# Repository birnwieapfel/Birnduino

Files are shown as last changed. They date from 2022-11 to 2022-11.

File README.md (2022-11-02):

# birnduino
An Arduino clone with an RS232 serial interface.

In 2013, I bought a board call "Freeduino Serial v2.0", which is an Arduino clone having an RS232 serial interface using a MAX232. But it seems that it is not available anymore now and I could not find the original files of the "v2.0". So I decided to create my own based on some information about the Freeduino I found in the internet and having a look at my "Freeduino Serial v2.0" board...

## Repository content
- The [inputs folder](inputs) contains the resources which helped me to create the schematic and PCB
- The [datasheets folder](datasheets) contains the datasheets for the used ICs
- The KiCad 6.0 files for the schematic and PCB are in the [KiCad subfolder](KiCad)
- *to come...* Image(s) of the PCB can be found in the folder *images*

## Old resouces
Here are some links which helped to realize this project:
- https://thdarduino.blogspot.com/2015/12/freeduino-serial-v20-bausatz.html

## Other links
- https://freeduino.org/freeduino_open_designs-html
- https://github.com/WestfW/Freeduino-historical

## License
Copyright 2022, Robert Birn. All Rights Reserved.

"birnduino" is licensed under [CC BY-SA 4.0](https://creativecommons.org/licenses/by-sa/4.0/legalcode) by Robert Birn.

This work, "birnduino", is a derivative of "Freeduino Serial" by CircuitJoy and Spiffed, released under CC BY-SA 2.5. 

"Freeduino Serial" is based on the Arduino Diecimila reference design (www.arduino.cc/main/ArduinoBoardDiecimila).

I started the work by using the **Arduino KiCad Library**, available here: https://github.com/Alarm-Siren/arduino-kicad-library. Remark: After an update, no reference to this library is existing anymore.

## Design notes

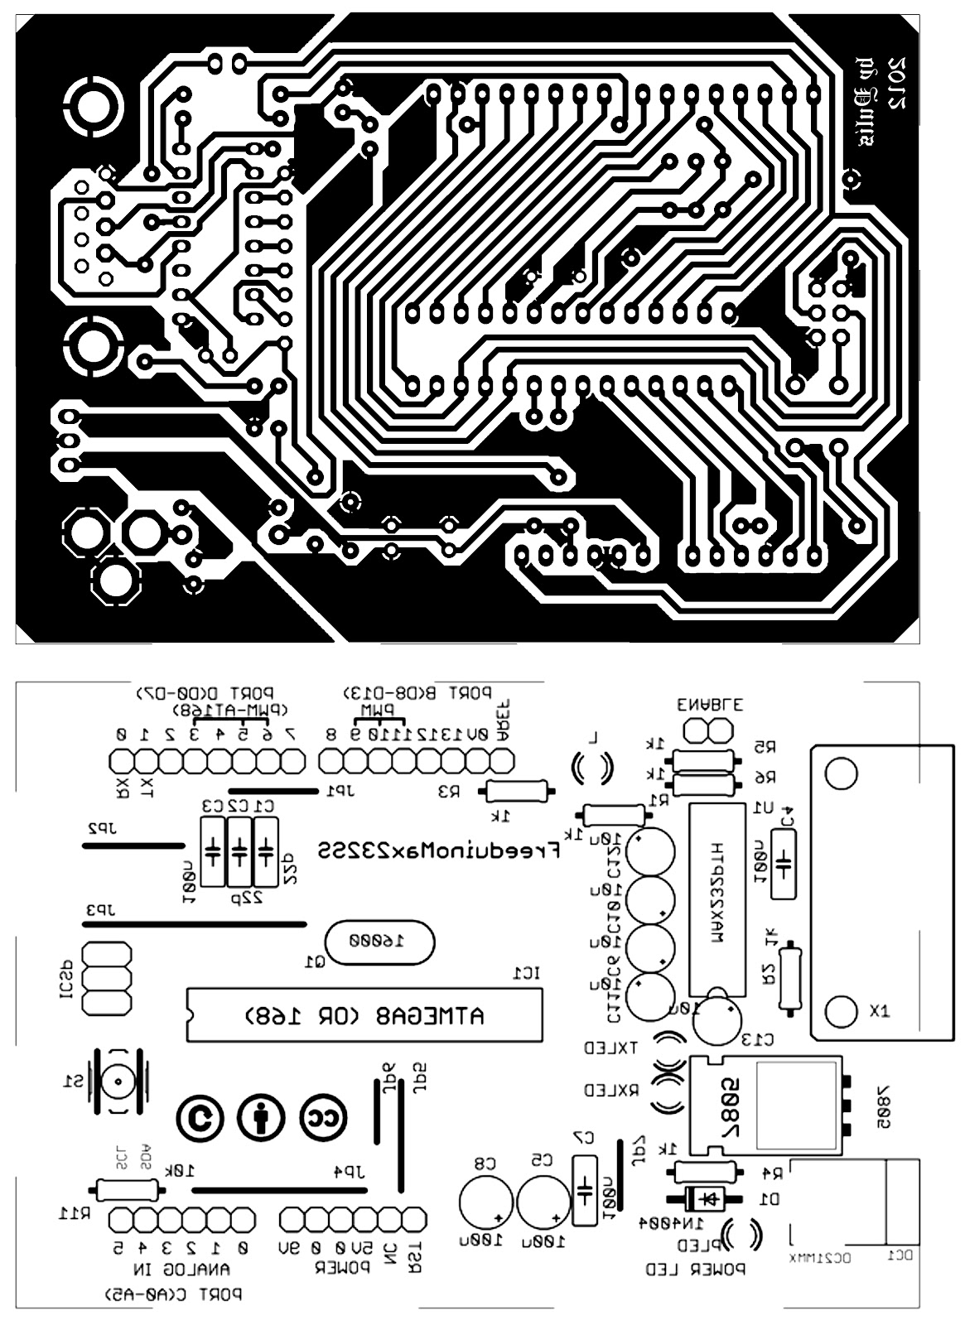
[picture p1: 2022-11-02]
inputs/arduino-serial-board-pcb.jpg

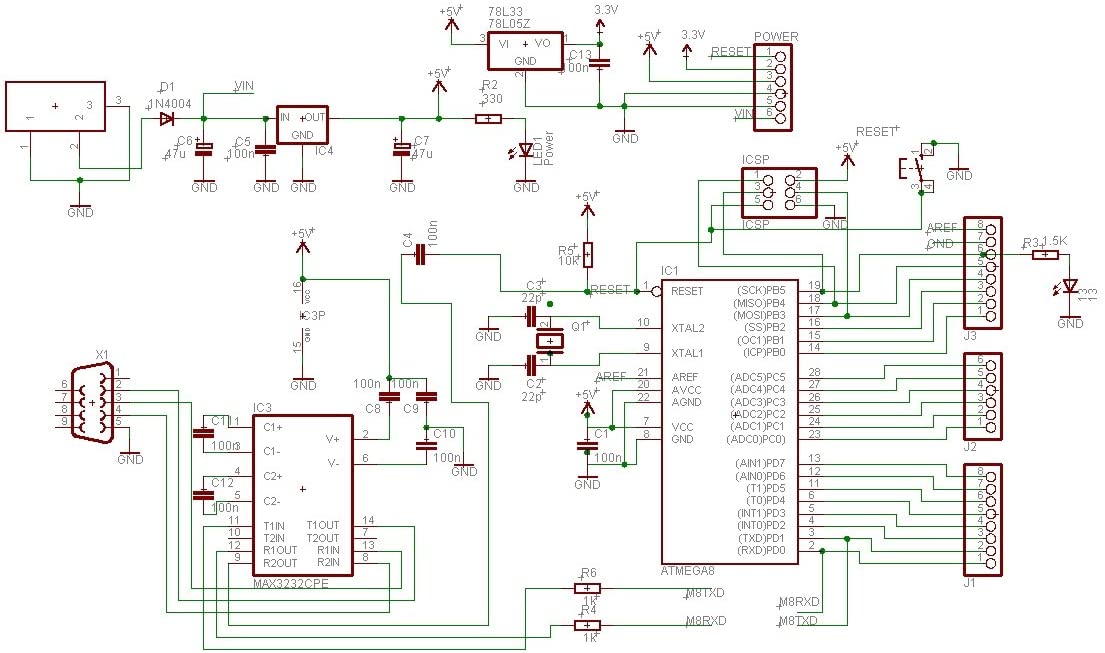
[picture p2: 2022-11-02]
inputs/arduino-serial-board-v2.0.jpg

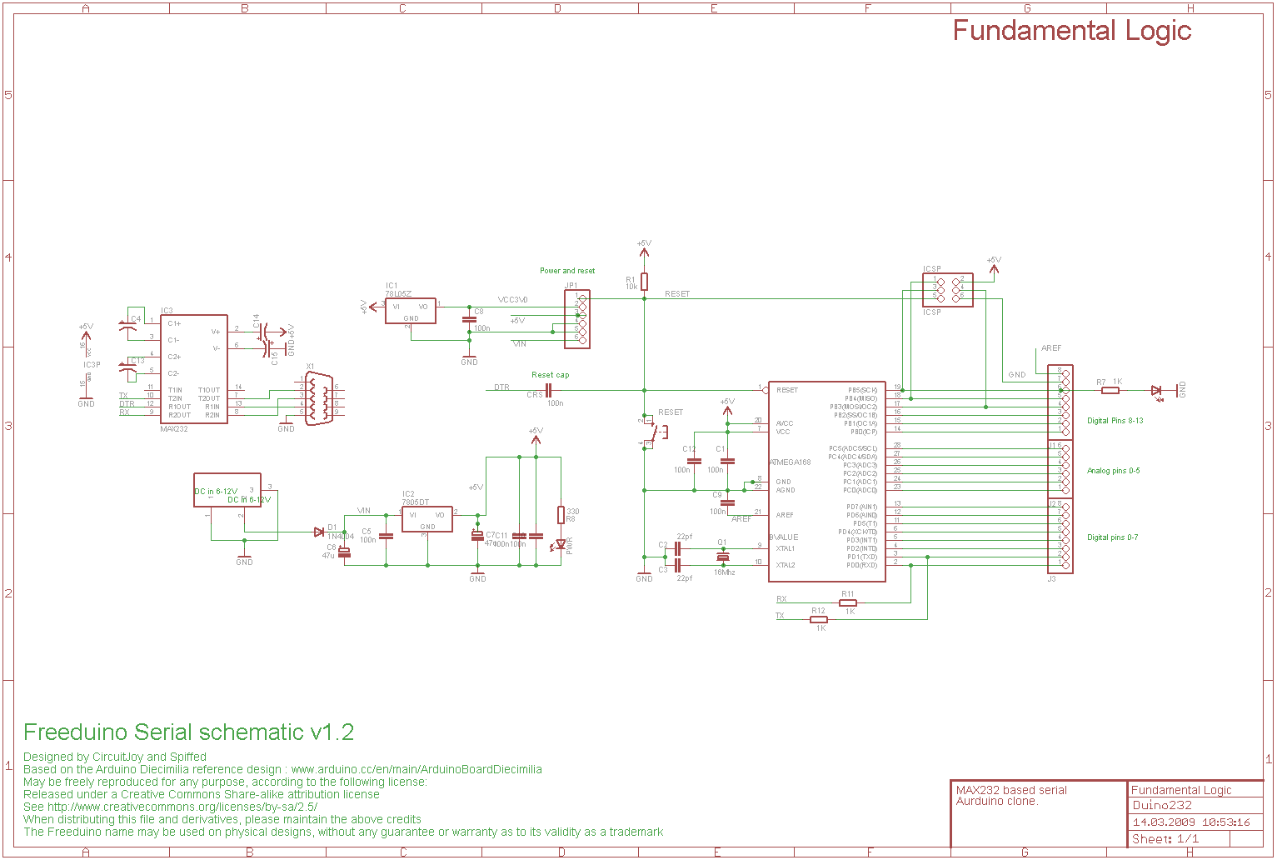
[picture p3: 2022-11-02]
inputs/freeduino_MaxSerial_scheme.gif

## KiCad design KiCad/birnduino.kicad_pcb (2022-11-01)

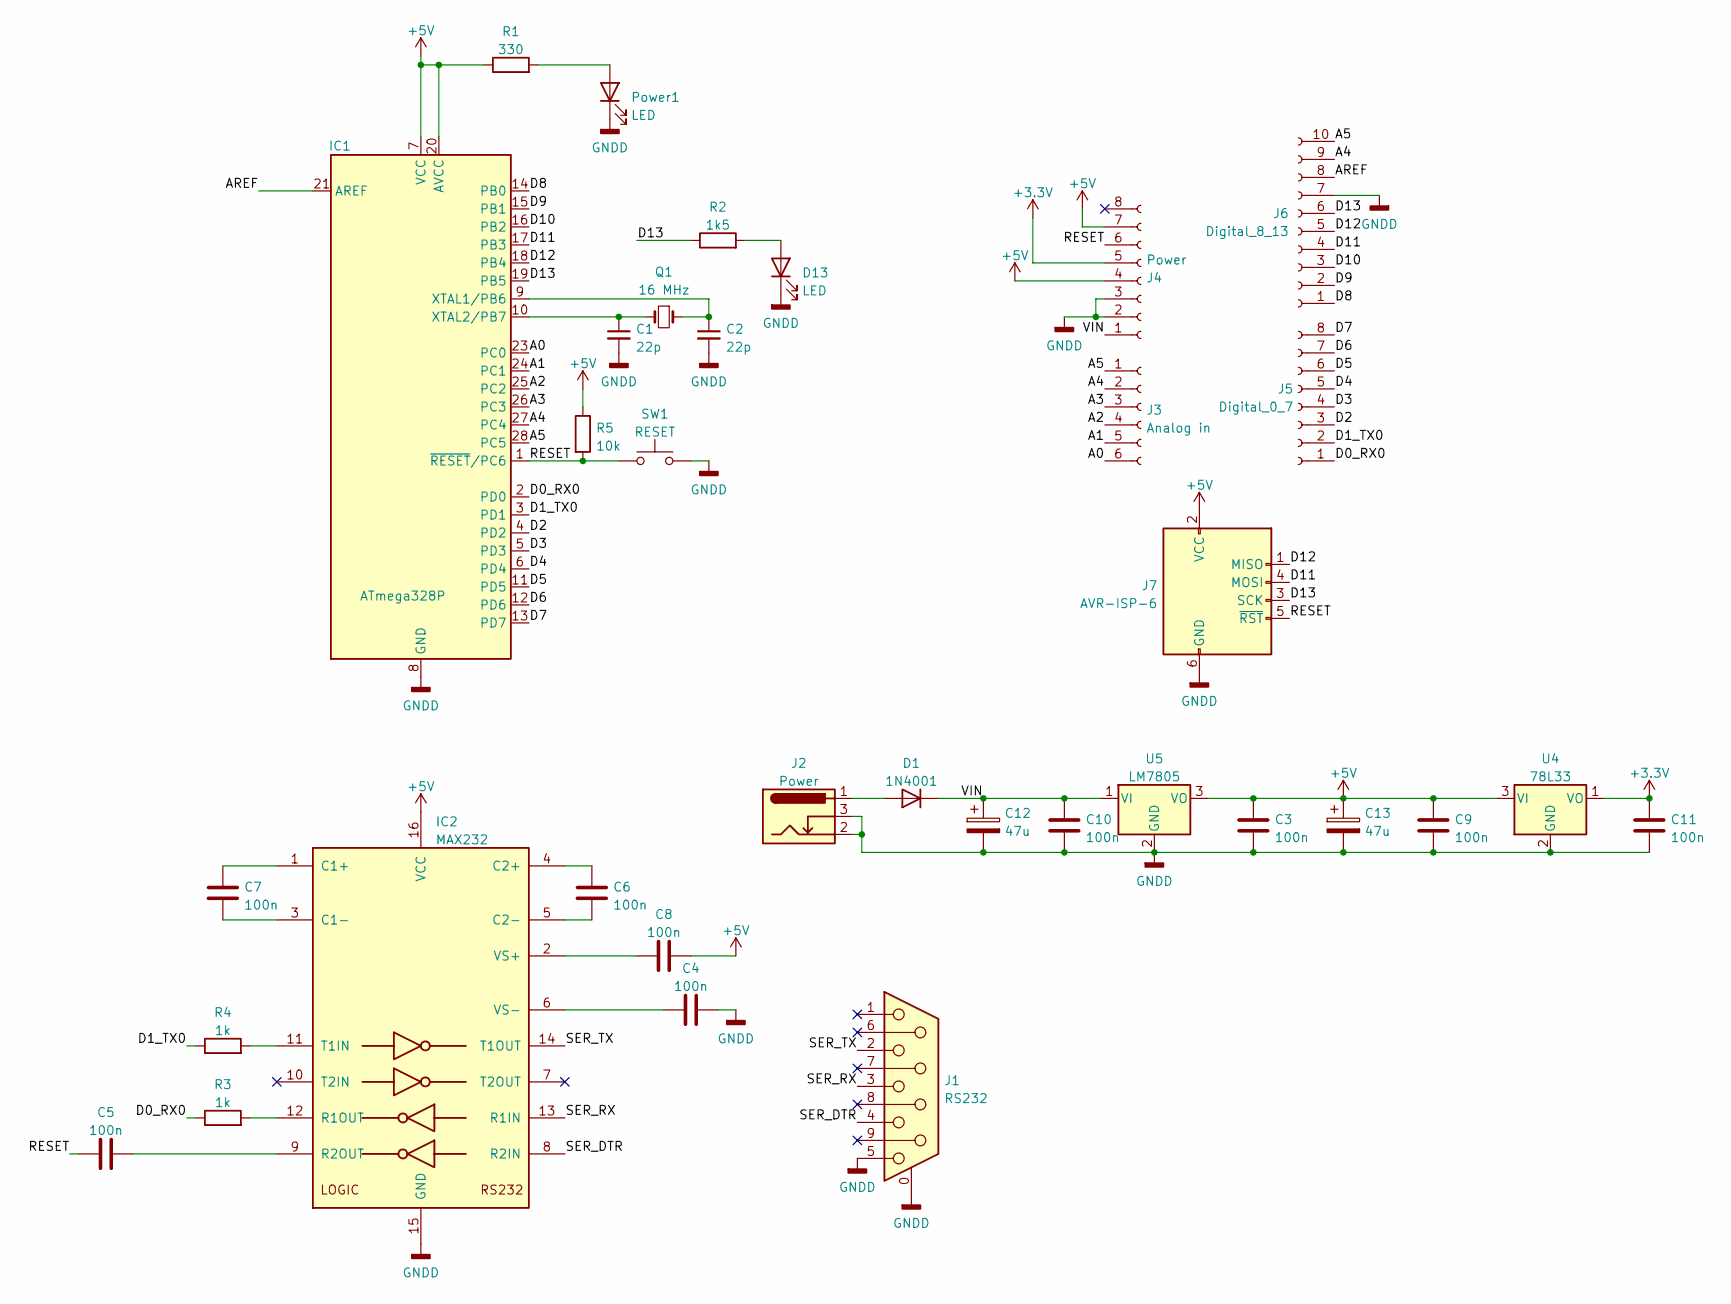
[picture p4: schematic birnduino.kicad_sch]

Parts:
C1, C2: 22p; C_Rect_L7.0mm_W2.0mm_P5.00mm
C3, C4, C5, C6, C7, C8, C9, C10, C11: 100n; C_Rect_L7.0mm_W2.0mm_P5.00mm
C12, C13: 47u; CP_Radial_D6.3mm_P2.50mm
D1: 1N4001; D_DO-41_SOD81_P10.16mm_Horizontal
D13: LED; LED_D3.0mm
IC1: ATmega328P; DIP-28_W7.62mm
IC2: MAX232; DIP-16_W7.62mm
J1: RS232; DSUB-9_Female_Horizontal_P2.77x2.84mm_EdgePinOffset7.70mm_H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
J2: Power; BarrelJack_Horizontal
J3: Analog in; PinSocket_1x06_P2.54mm_Vertical
J4: Power; PinSocket_1x08_P2.54mm_Vertical
J5: Digital_0_7; PinSocket_1x08_P2.54mm_Vertical
J6: Digital_8_13; PinSocket_1x10_P2.54mm_Vertical
J7: AVR-ISP-6; PinHeader_2x03_P2.54mm_Vertical
Power1: LED; LED_D3.0mm
Q1: 16 MHz; Crystal_HC49-U_Vertical
R1: 330; R_Axial_DIN0207_L6.3mm_D2.5mm_P10.16mm_Horizontal
R2: 1k5; R_Axial_DIN0207_L6.3mm_D2.5mm_P10.16mm_Horizontal
R3, R4: 1k; R_Axial_DIN0207_L6.3mm_D2.5mm_P10.16mm_Horizontal
R5: 10k; R_Axial_DIN0207_L6.3mm_D2.5mm_P10.16mm_Horizontal
SW1: RESET; SW_PUSH_6mm
U4: 78L33; TO-92_Inline
U5: LM7805; TO-220-3_Vertical

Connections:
+3V3: C11.1, J4.5, U4.1 (VO)
+5V: C3.1, C8.1, C9.1, C13.1, IC1.7 (VCC), IC1.20 (AVCC), IC2.16 (VCC), J4.4, J4.7, J7.2 (VCC), R1.1, R5.1, U4.3 (VI), U5.3 (VO)
/A0: IC1.23 (PC0), J3.6
/A1: IC1.24 (PC1), J3.5
/A2: IC1.25 (PC2), J3.4
/A3: IC1.26 (PC3), J3.3
/A4: IC1.27 (PC4), J3.2, J6.9
/A5: IC1.28 (PC5), J3.1, J6.10
/AREF: IC1.21 (AREF), J6.8
/D0_RX0: IC1.2 (PD0), J5.1, R3.1
/D1_TX0: IC1.3 (PD1), J5.2, R4.1
/D2: IC1.4 (PD2), J5.3
/D3: IC1.5 (PD3), J5.4
/D4: IC1.6 (PD4), J5.5
/D5: IC1.11 (PD5), J5.6
/D6: IC1.12 (PD6), J5.7
/D7: IC1.13 (PD7), J5.8
/D8: IC1.14 (PB0), J6.1
/D9: IC1.15 (PB1), J6.2
/D10: IC1.16 (PB2), J6.3
/D11: IC1.17 (PB3), J6.4, J7.4 (MOSI)
/D12: IC1.18 (PB4), J6.5, J7.1 (MISO)
/D13: IC1.19 (PB5), J6.6, J7.3 (SCK), R2.1
/RESET: C5.2, IC1.1 (~RESET/PC6), J4.6, J7.5 (~RST), R5.2, SW1.1
/SER_DTR: IC2.8 (R2IN), J1.4
/SER_RX: IC2.13 (R1IN), J1.3
/SER_TX: IC2.14 (T1OUT), J1.2
/VIN: C10.1, C12.1, D1.1 (K), J4.1, U5.1 (VI)
GNDD: C1.2, C2.2, C3.2, C4.2, C9.2, C10.2, C11.2, C12.2, C13.2, D13.1 (K), IC1.8 (GND), IC1.22 (GND), IC2.15 (GND), J1.0 (PAD), J1.5, J2.2, J2.3, J4.2, J4.3, J6.7, J7.6 (GND), Power1.1 (K), SW1.2, U4.2 (GND), U5.2 (GND)
unnamed: C1.1, IC1.10 (XTAL2/PB7), Q1.2
unnamed: C2.1, IC1.9 (XTAL1/PB6), Q1.1
unnamed: C4.1, IC2.6 (VS-)
unnamed: C5.1, IC2.9 (R2OUT)
unnamed: C6.1, IC2.4 (C2+)
unnamed: C6.2, IC2.5 (C2-)
unnamed: C7.1, IC2.1 (C1+)
unnamed: C7.2, IC2.3 (C1-)
unnamed: C8.2, IC2.2 (VS+)
unnamed: D1.2 (A), J2.1
unnamed: D13.2 (A), R2.2
unnamed: IC2.11 (T1IN), R4.2
unnamed: IC2.12 (R1OUT), R3.2
unnamed: Power1.2 (A), R1.2

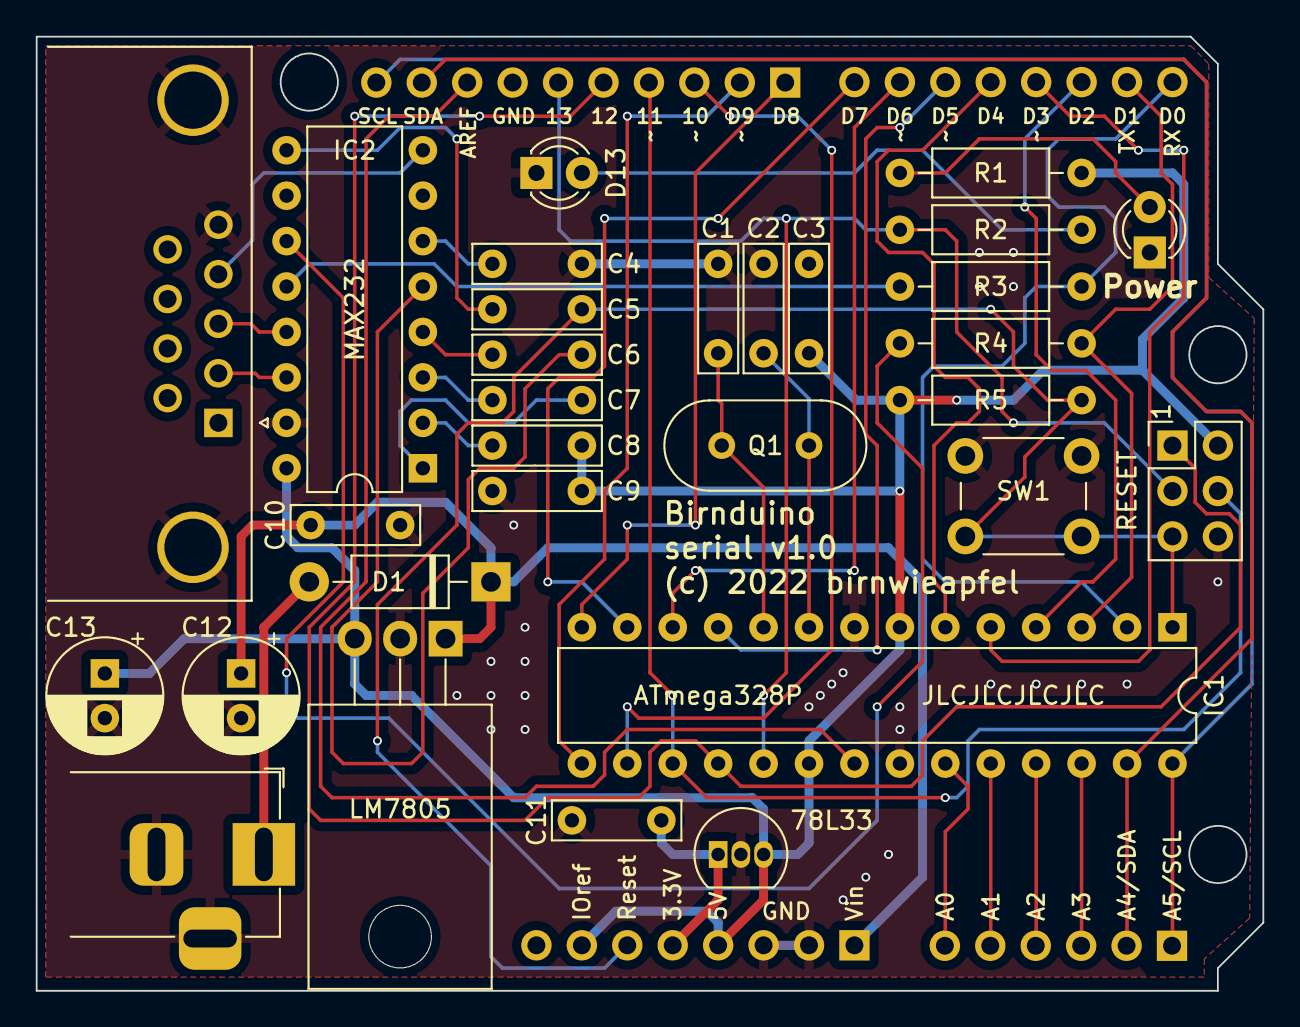
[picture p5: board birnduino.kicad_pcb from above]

Board: 2 copper layers, 68.6 x 53.3 mm, 34 parts (0 on the bottom side), 43 nets.

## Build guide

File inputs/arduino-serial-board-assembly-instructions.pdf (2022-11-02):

Arduino Serial v2.0 Board
Courtesy of MCUKits

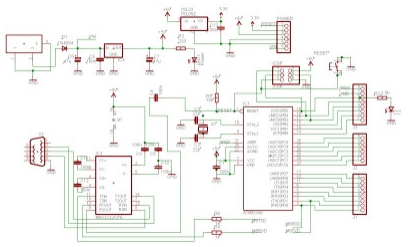
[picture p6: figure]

The Arduino diecimila compatible Freeduino serial board is a special version of the Arduino serial board designed by NKC Electronics. The board is diecimila compatible (autoreset) and includes the 13 digital pin LED for easy diagnostics and basic LED sketch execution. The v2.0 board uses a MAX232 compatible chip for interfacing with RS232. The older v1.0 board used two transistors, but had some reliability issues with auto-reset and sketch uploading. First, unpack the kit and start with the PCB.

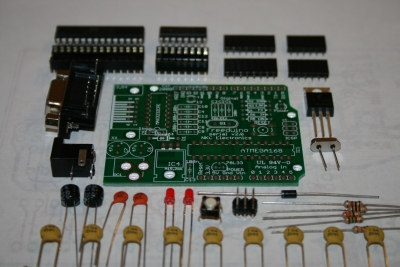
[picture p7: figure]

Let’s start with the power portion of the schematic using the following parts:

DC1 | DC power jack
D1 | 1N4004 diode
C5 | 100nF ceramic capacitor
C6, C7 | 47uF electrolytic capacitor
IC2 | 7805 5V positive voltage regulator
Power LED | 3mm LED
R2 | 330 ohm resistor

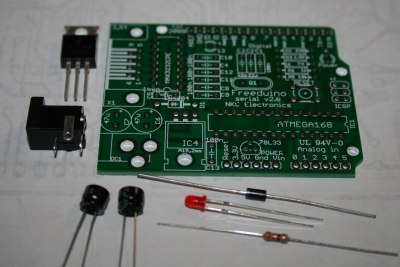
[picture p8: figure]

Plug a wall plug voltage regulator (+7V to +12V). The LED lights up, indicating that the Power supply is working.
NOTE: This board is shields friendly as the 7805 voltage regulator is mounted horizontally.

Next continue with the soldering of the RS232 components:

X1 | DB9 female PCB adapter
IC3 | 16-pin IC socket
C4, C8, C9, C10, C11, C12 | 0.1uF (100nF) ceramic capacitors

Solder the rest of the components:

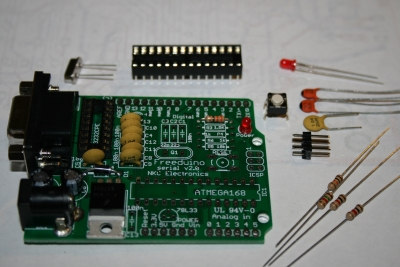
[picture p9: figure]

R3 | 1.5Kohm resistor
R4, R6 | 1 Kohm resistor
R5 | 10 Kohm resistor
C2, C3 | 22pF ceramic capacitor
C1 | 0.1uF (100nF) ceramic capacitor
13 3mm LED (Arduino pin 13 status LED)
Q1 | 16 MHz crystal

RESET | Reset switch
IC1 | 28-pin IC socket
ICSP | 2×3 pin male header

Now solder the headers and sockets:

POWER & Analog In | 6-pin female header
Digital | 2 x 8-pin female header

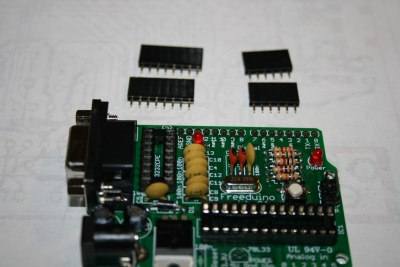
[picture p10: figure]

Pay special attention to the alignment of the female headers.

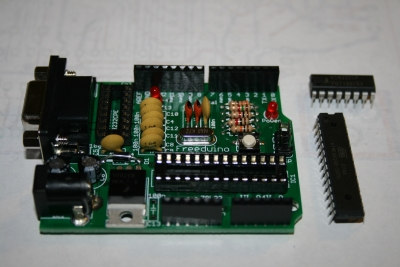
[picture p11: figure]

And finally install the ATMEGA168 MCU and the MAX232 (or HIN232 / ICL232) chips.

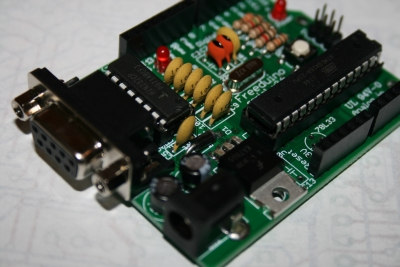
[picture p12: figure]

The board is ready to be used. Start the Arduino IDE and load the BLINK sketch from the examples directory. Verify that ATMEGA168 is selected in Tools –> Microcontroller (MCU) and Arduino Diecimila in the Tools –> board option. Select the COM port number corresponding to the serial interface where the Freeduino serial board is connected to. Press the “Upload to I/O board” button in Arduino and the board should autoreset and complete the programming. If you selected correctly the BLINK sketch, the LED “13″ must start blinking once every 2 second (0.5Hz).

The board has space for an optional 3.3V regulator (78L33 TO-92 footprint) with it’s associated decoupling 0.1uF capacitor (C13).

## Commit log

2022-11-01 Fixed some issues detected by ERC. No impact on board layout.
    [birnduino.kicad_sch]
2022-11-01 Update of board/library to change D-SUB connector and power jack.
    [birnduino.kicad_pcb, birnduino.kicad_sch]
2022-11-01 Removed dependencies to Arduino KiCad Library
    [birnduino.kicad_pcb, birnduino.kicad_sch]
2022-11-01 Removed Arduino KiCad Library
2022-11-01 Update of gerber files
    [birnduino-B_Cu.gbl, birnduino-B_Mask.gbs, birnduino-B_Paste.gbp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]
2022-11-01 Removed J1 and J2 labels
    [birnduino-B_Cu.gbl, birnduino-B_Mask.gbs, birnduino-B_Paste.gbp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]
2022-11-02 Restructured repository and added additional files
    [birnduino-B_Cu.gbl, birnduino-B_Mask.gbs, birnduino-B_Paste.gbp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]

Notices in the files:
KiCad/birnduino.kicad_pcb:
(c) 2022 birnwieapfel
